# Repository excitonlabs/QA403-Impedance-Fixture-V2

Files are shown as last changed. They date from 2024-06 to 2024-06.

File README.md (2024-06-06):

# QA403 Impedance Fixture V2

A test fixture for the QuantAsylum QA403 for measuring impedance based on Matt's blog posts:
* https://quantasylum.com/blogs/news/speaker-impedance-measurements
* https://quantasylum.com/blogs/news/measuring-input-impedance

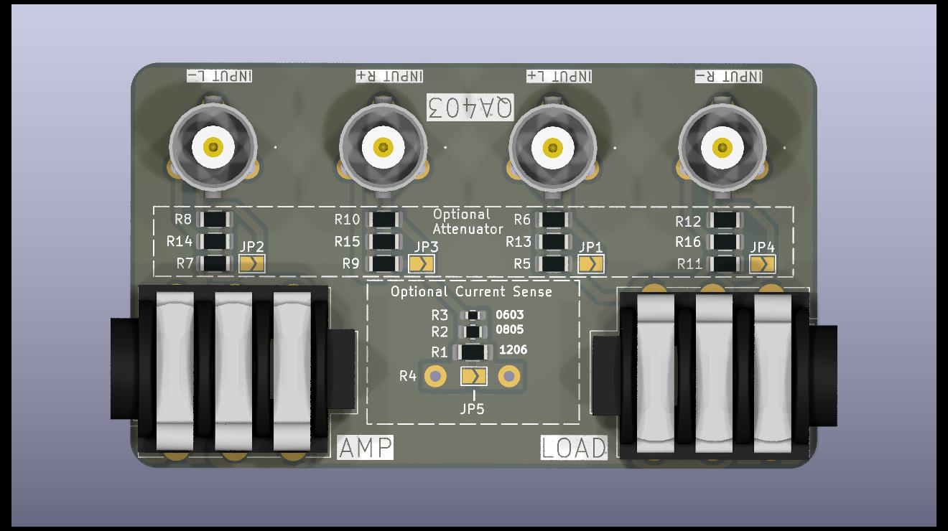
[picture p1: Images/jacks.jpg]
PCB only


This is version two of the text fixture and adds
 * optional attenuation before the inputs to the analyser
 * optional current sense resistor if you just want to use the board for connectivity.

The PCB is fairly flexible, there are three footprints for SMD currents sense resistors and a single through-hole footprint. These are in parallel so the expectation is you place one. The PCB also had an additional BNC for the L- input which may be useful for balanced measurements (BTL etc.).

## Using the attenuators

The analyser cannot have input voltages above 40V RMS, for use with high power amplifiers attenuation is needed. Three resistors form a T-pad before each input that can be used to preserve impedance if need. Alternatively, the T-pad can be reduced to a simple voltage divider by using a 0r resistor in the position before the coaxial socket.

### -6 dB attenuation using voltage divider

Place the following components to reduce the voltage the analysers measured by -6dBV:

* R5, R7, R9, R12 = 0r

* R6, R8, R10, R11, R13, R14, R15, R16 = 3k3

* All jumpers are open-circuit.

Voltage divider is a better option in general because it introduces less noise due to the lower resistances.

### -10dB attenuation using T-pad

Place the following components to reduce the voltage the analysers measured by -10dBV:

* R5, R6, R7, R8, R9, R10, R11, R12 = 52k

* R13, R14, R15, R16 = 72k

* All jumpers are open-circuit.

### Using the current sense

The right channel measures the voltage drop across the current sense resistor. Place an SMD resistor in any of the positions: R1, R2, R3, or R4. All of these are connected in parallel, so you can place more than one if you wish, just work out the resulting value. The smaller the resisor value the more noise will appear in the current measurement, the larger the resistor value the more it will load the circuit. Try and use a current sense 100 to 10 times smaller than the load.

### Disabling the attenuator

Do not place any resistors and short solder jumpers JP1, JP2, JP3, JP4.

### Disabling the current sense resistor

Short the solder jumper JP5.

## Questions

Forum post https://forum.quantasylum.com/t/comments-welcomed-on-test-fixture-pcb-for-impedance-measurements

## How to get this PCB

1. Order PCBs from a fab. house such as https://jlcpcb.com or email me, I have a few spare ones.
2. Order components from the BOM

## BOM

See datasheets in `/Parts` directory.

* Optional 2 x [MKDSN 1,5/ 2-5,08 1729128, terminal block](https://www.phoenixcontact.com/en-us/products/printed-circuit-board-terminal-mkdsn-15-2-508-1729128)
* Optional 2 x [Neutrik NMJ6HCD2, Jack socket](https://www.neutrik.com/en/product/nmj6hcd2)
* 4  x [TE Connectivity 5221123-2, BNC socket](https://www.te.com/usa-en/product-5221123-2.html)
* 1 x current sense resistor of the following types:
  * 2012 (5025)
  * 1206 (3216)
  * 0805 (2012)
  * Through-hole 

## Examples

PCB with jack sockets
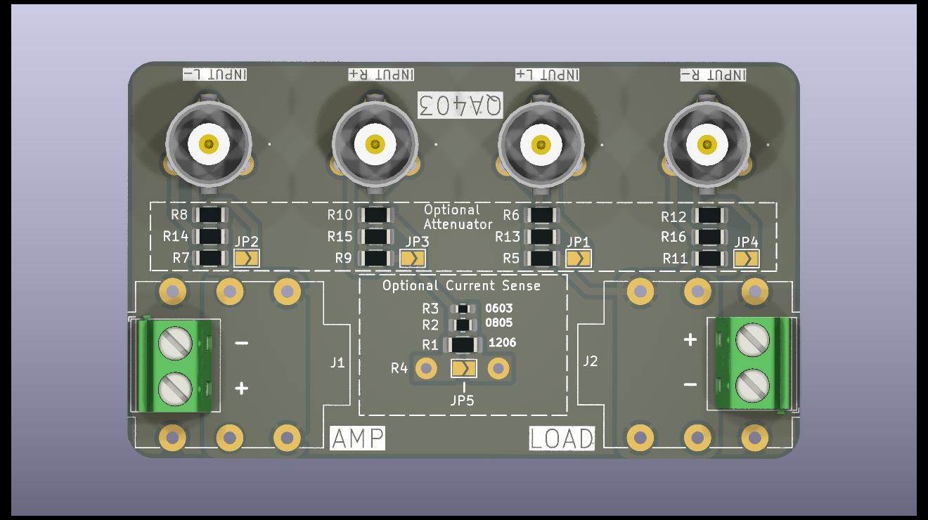
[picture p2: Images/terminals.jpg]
PCB with terminals

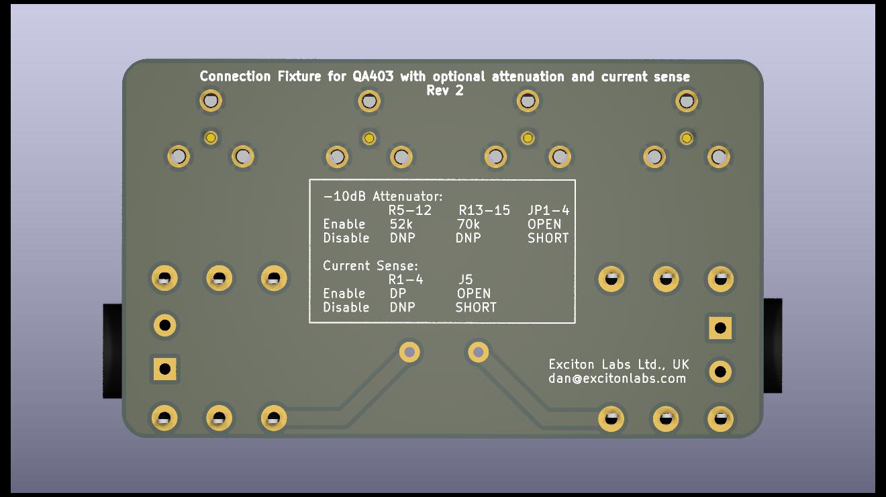
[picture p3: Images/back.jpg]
PCB's back


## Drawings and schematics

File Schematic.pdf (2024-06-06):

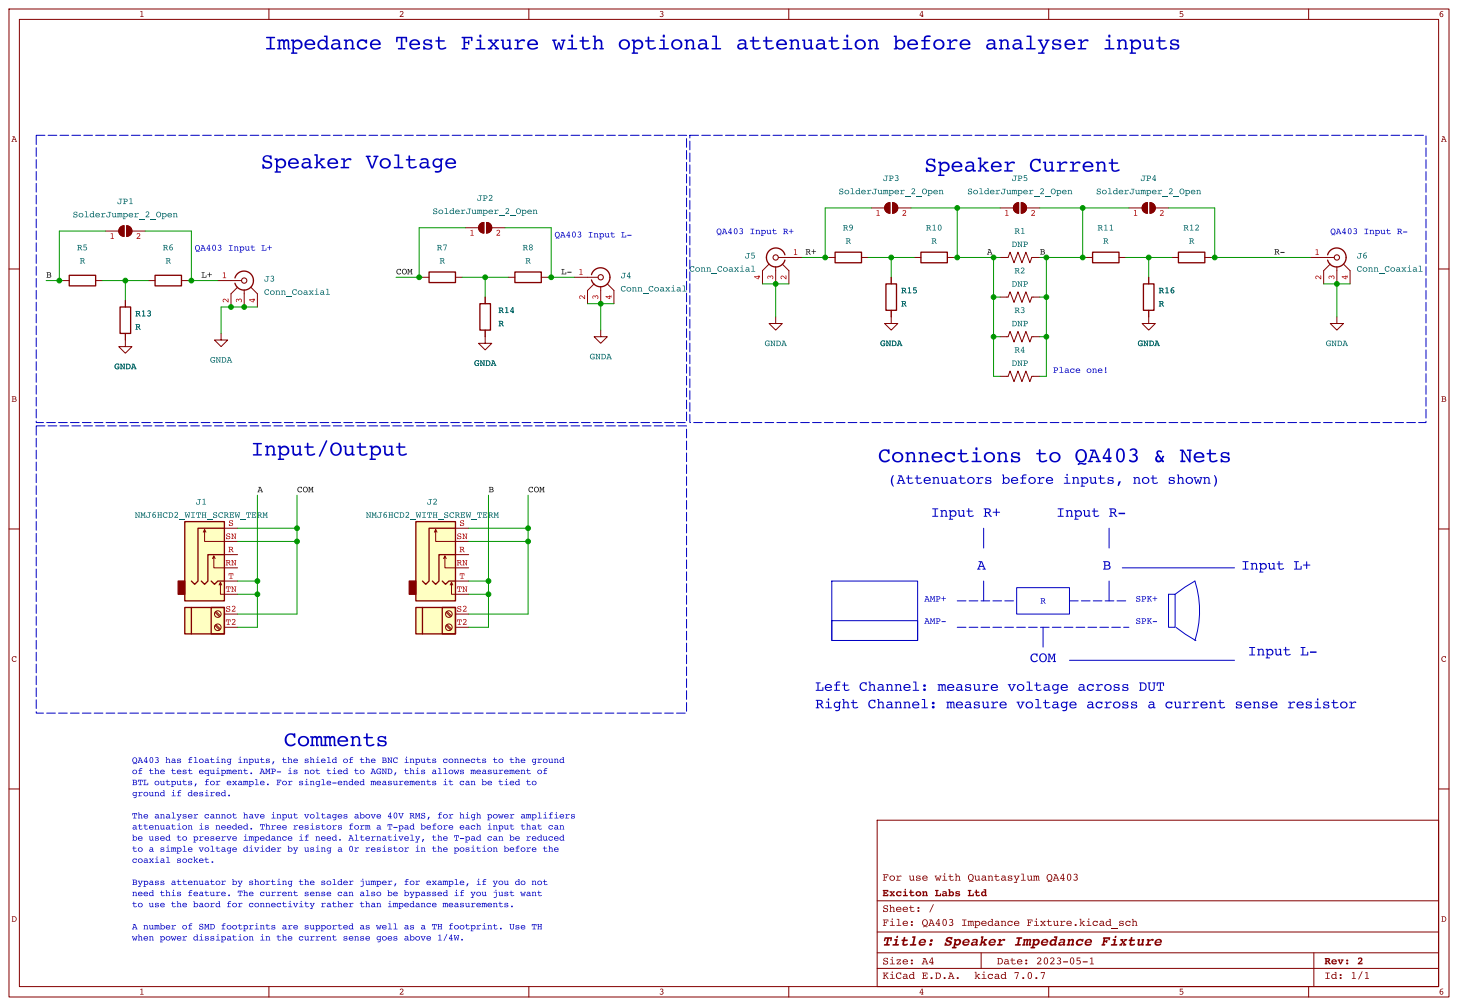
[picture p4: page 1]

For use with Quantasylum QA403

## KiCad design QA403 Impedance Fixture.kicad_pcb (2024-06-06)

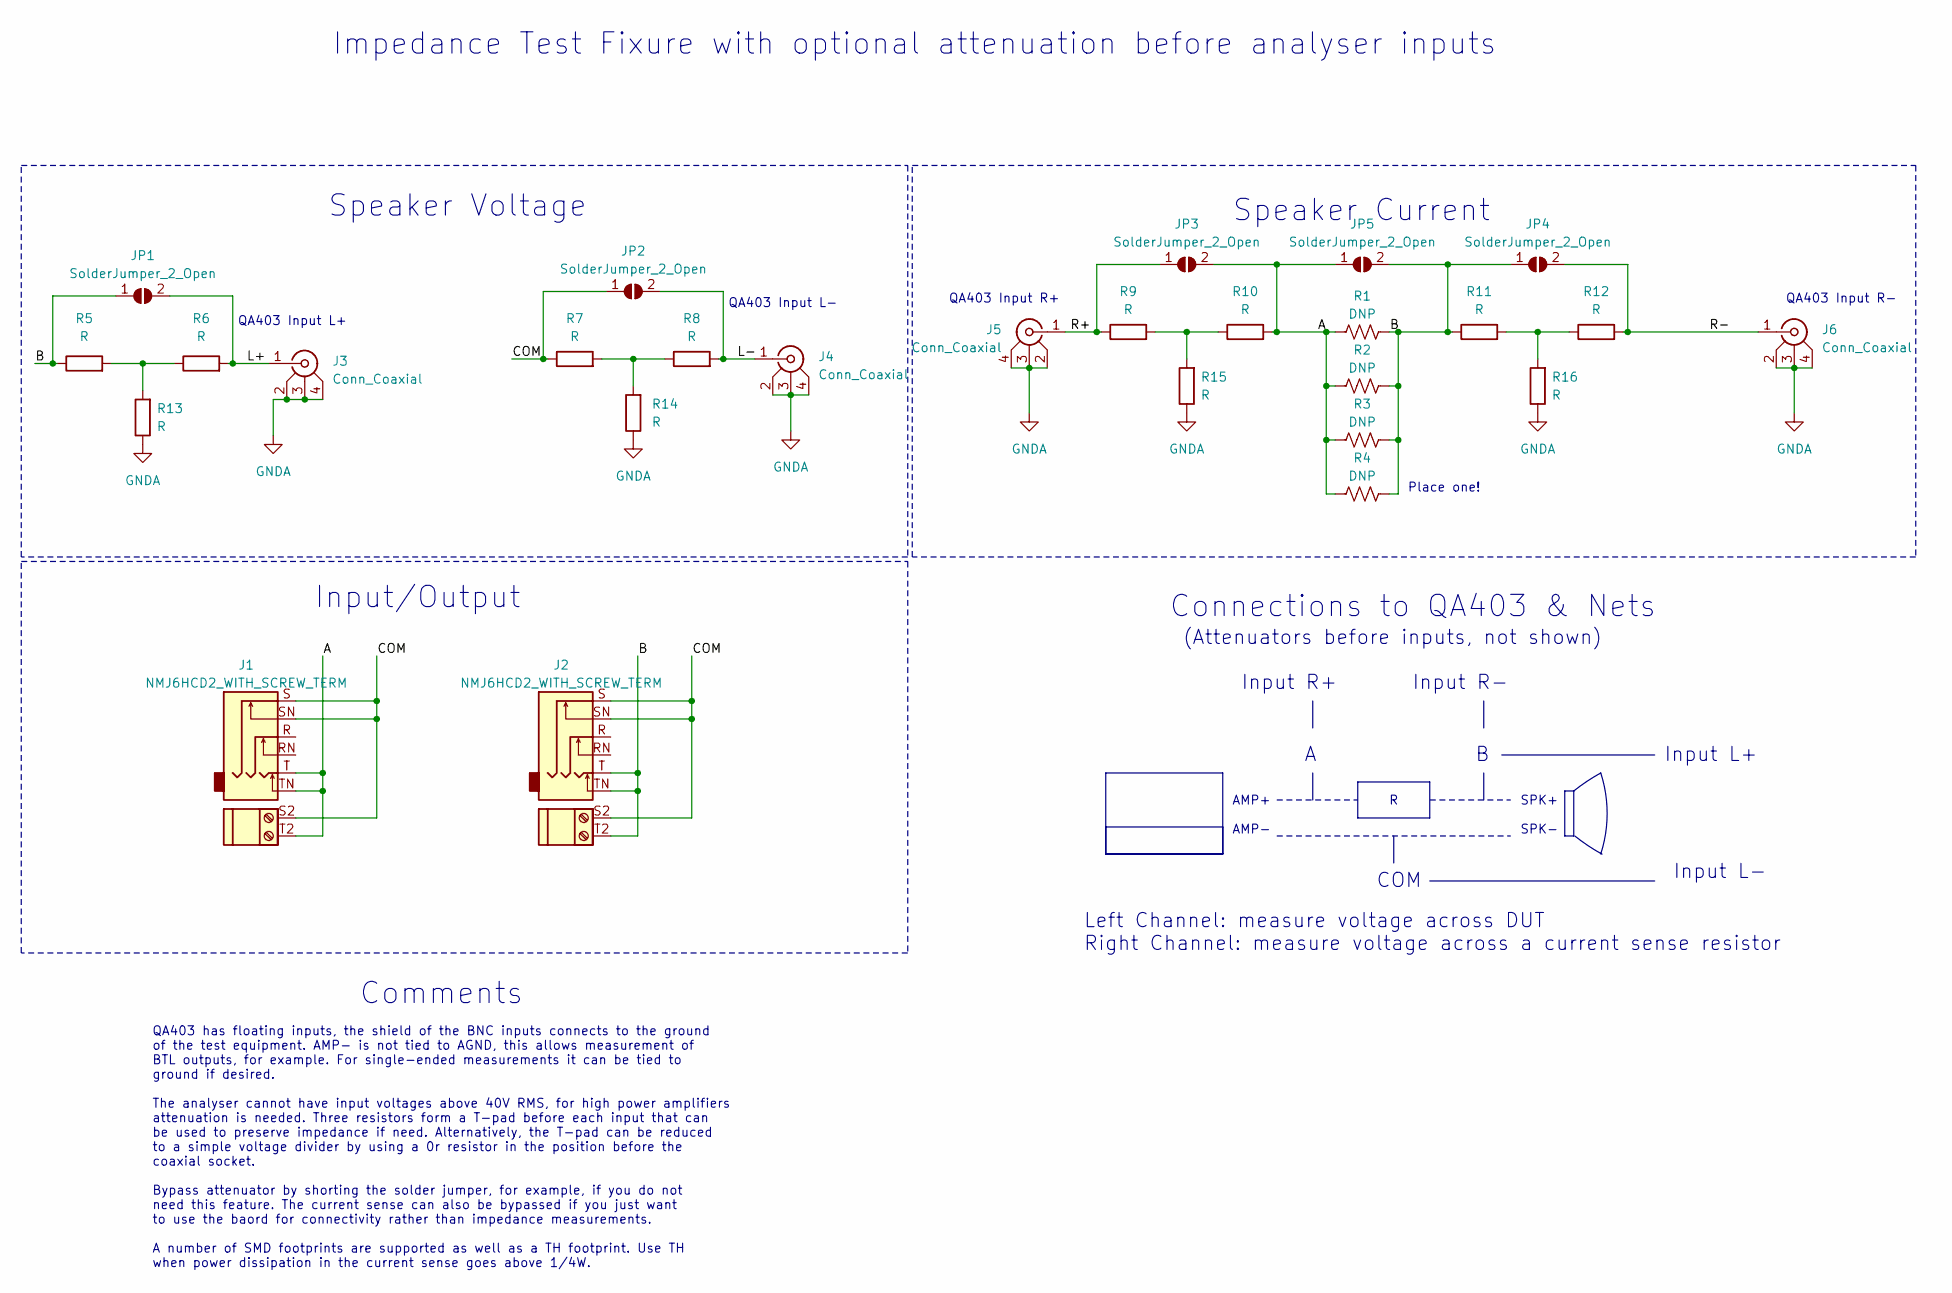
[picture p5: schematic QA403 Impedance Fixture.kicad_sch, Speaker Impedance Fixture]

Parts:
J1, J2: NMJ6HCD2_WITH_SCREW_TERM; Dual_Jack_6.35mm_Neutrik_NMJ6HCD2_Horizontal_TerminalBlock_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
J3, J4, J5, J6: Conn_Coaxial; 52211232
JP1, JP2, JP3, JP4, JP5: SolderJumper_2_Open; SolderJumper-2_P1.3mm_Open_TrianglePad1.0x1.5mm
R1: DNP; R_1206_3216Metric_Pad1.30x1.75mm_HandSolder
R2: DNP; R_0805_2012Metric_Pad1.20x1.40mm_HandSolder
R3: DNP; R_0603_1608Metric_Pad0.98x0.95mm_HandSolder
R4: DNP; R_SQM_20W_Resistor_45mm_20mm_12mm
R5, R6, R7, R8, R9, R10, R11, R12, R13, R14, R15, R16: R; R_1206_3216Metric

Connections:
/A: J1.T, J1.T2, J1.TN, JP3.2 (B), JP5.1 (A), R1.1, R2.1, R3.1, R4.1, R10.2
/B: J2.T, J2.T2, J2.TN, JP1.1 (A), JP4.1 (A), JP5.2 (B), R1.2, R2.2, R3.2, R4.2, R5.1, R11.1
/COM: J1.S, J1.S2, J1.SN, J2.S, J2.S2, J2.SN, JP2.1 (A), R7.1
/L+: J3.1 (In), JP1.2 (B), R6.2
/L-: J4.1 (In), JP2.2 (B), R8.2
/R+: J5.1 (In), JP3.1 (A), R9.1
/R-: J6.1 (In), JP4.2 (B), R12.2
GNDA: J3.2 (Ext), J3.3 (Ext), J3.4 (Ext), J4.2 (Ext), J4.3 (Ext), J4.4 (Ext), J5.2 (Ext), J5.3 (Ext), J5.4 (Ext), J6.2 (Ext), J6.3 (Ext), J6.4 (Ext), R13.1, R14.1, R15.1, R16.1
unnamed: R9.2, R10.1, R15.2
unnamed: R11.2, R12.1, R16.2
unnamed: R5.2, R6.1, R13.2
unnamed: R7.2, R8.1, R14.2

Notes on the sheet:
Speaker Current
Impedance Test Fixure with optional attenuation before analyser inputs
Speaker Voltage
QA403 Input R+
QA403 Input L+
(Attenuators before inputs, not shown)
Input L+
QA403 has floating inputs, the shield of the BNC inputs connects to the ground of the test equipment. AMP- is not tied to AGND, this allows measurement of BTL outputs, for example. For single-ended measurements it can be tied to ground if desired. The analyser cannot have input voltages above 40V R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
Input L-
Input/Output
AMP+ AMP-
Input R-
SPK+ SPK-
Comments
Input R+
QA403 Input R-
Left Channel: measure voltage across DUT Right Channel: measure voltage across a current sense resistor
QA403 Input L-
Connections to QA403 & Nets
COM
Place one!

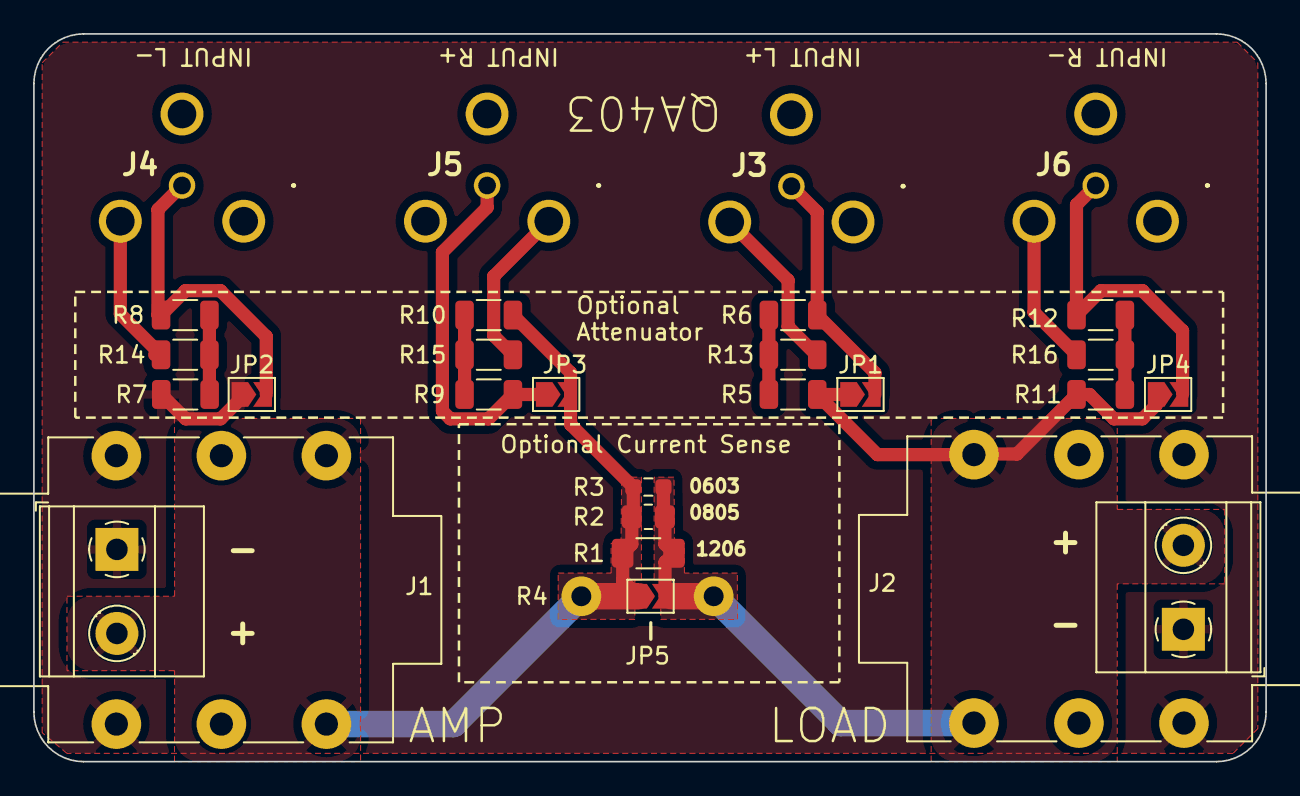
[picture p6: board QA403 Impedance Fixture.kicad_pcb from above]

Board: 2 copper layers, 74.5 x 44.0 mm, 27 parts (0 on the bottom side), 12 nets.
